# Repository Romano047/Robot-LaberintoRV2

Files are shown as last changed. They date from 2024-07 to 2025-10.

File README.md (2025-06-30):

# Robot-LaberintoRV2
Robot Laberinto R 2024-2025

Proyecto realizado en la Escuela de Educación Secundaria Técnica N°5 "2 de Abril" Temperley, Buenos Aires, Argentina. Desarrollado por Iván Romano, estudiante de Electrónica de la institución a cargo del profesor Ing. Martín Leguizamón.

El objetivo de este reoositrio es el de desarrollar un robot autónomo de competición dentro de la categoría de "Robot Laberinto". 

Se tomarán como referencia en su elaboración las reglas actualmente vigentes (2024) dentro de la Liga Nacional de Robótica (LNR) en la categoría de "Laberinto". 

# Guía de Repositorio

- Hardware
  - KiCad: En ella se encuentran todos los archivos correspondientes al desarrollo del PCB.

- 3D
  - AutoCad: En esta carpeta se encuentran los archivos correspondientes al diseño 3D en conjunto a sus trazados a formato .stl para facilitar su posterior impresión. 

- Software
  - Ensayos: Ensayos básicos de cada funcionalidad o punto de interés de forma aislada que conforman el robot. (A su vez se encontrarán en el archivos correspondientes al robort de competición provincial "Alita").
  - LaberintoR2_v2: Versión del Software ejecutada actualmente en el robot. 

# Especificaciones

- Software: Desarrollado en C Orientado a Objetos, por medio del uso de VsCode en conjunto a su extensión PlatformIO.
- Desarrollo de PCBs: KiCad 7
- Placa de Desarrollo: Espressif ESP-32 WROOM DEV KIT
- Sensores de proximidad: HC-SR04
- Drivers de Motores: TB6612fng

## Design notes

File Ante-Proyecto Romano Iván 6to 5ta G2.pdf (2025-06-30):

ESCUELA DE EDUCACION SECUNDARIA TECNICA N° 5

“2 DE ABRIL” – TEMPERLEY – BUENOS AIRES

### ROBOT LABERINTO 2.0

MATERIA : | MONTAJES DE PROYECTOS ELECTRÓNICOS
GRUPO : | SPACE ANGELS

AUTORES:

Alumnos: Nombre y mail:
Iván Romano - romanoivan@industrialdetemperley.edu.ar

NOTAS:

PROFESOR: ING. MARTIN LEGUIZAMON

# Robot Laberinto

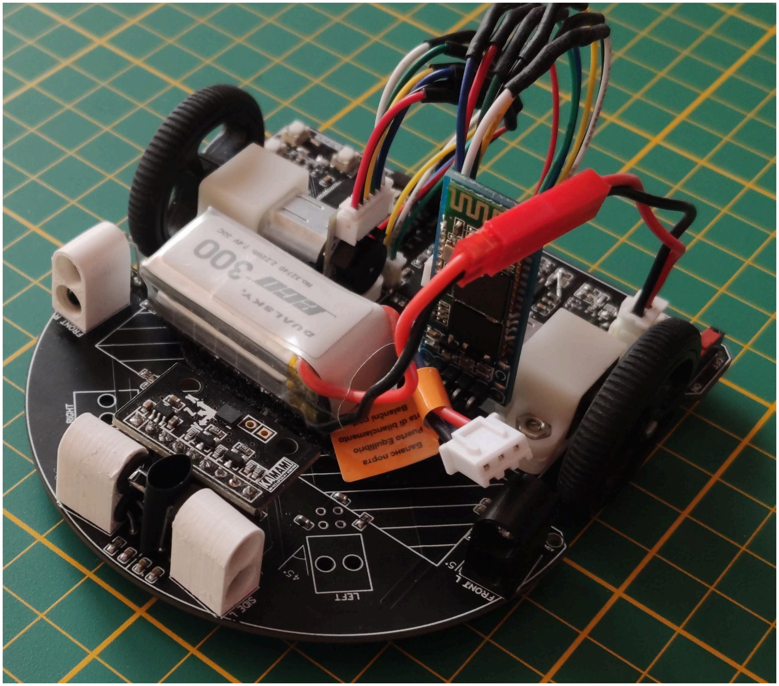
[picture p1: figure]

Robot laberinto capaz de evadir obstáculos y resolver caminos adversos de forma autónoma, con o sin asistencia parcial del usuario.

Este robot será sometido a situaciones en las que deberá decidir qué camino tomar, con tal de llegar a su objetivo nal en el menor tiempo posible y de la forma más eciente. Este decidirá según lo captado por los sensores. Contará con tres en total, uno al frente y dos a los laterales. Funcionan como una suerte de “ojos” con los que el robot reconocerá las paredes y los caminos libres para probar nuevas alternativas de resoluciones posibles.

Será programado por medio de Arduino, una IDE de código abierto, esto signica que es gratuito y accesible para todo el mundo. La placa de desarrollo empleada será el módulo ESP-32, el cual cuenta con Bluetooth y conexión wi, un controlador el cual cumplirá la función de ser el cerebro del proyecto. Este será quien controle y monitoree la información obtenida por los sensores, actuando en consecuencia, enviando órdenes a los motores, los cuales moverán al robot según lo observado.

Los motores serán los encargados de mover el robot según las órdenes enviadas por el módulo. El sentido de rotación será asignado por el “Puente H”, con el cual se regulará el sentido y la aceleración ordenada por medio de programación.

Este artefacto será alimentado por una batería LiPo de 7.4v apropiada para este tipo de elementos.

# ESQUEMA EN BLOQUES

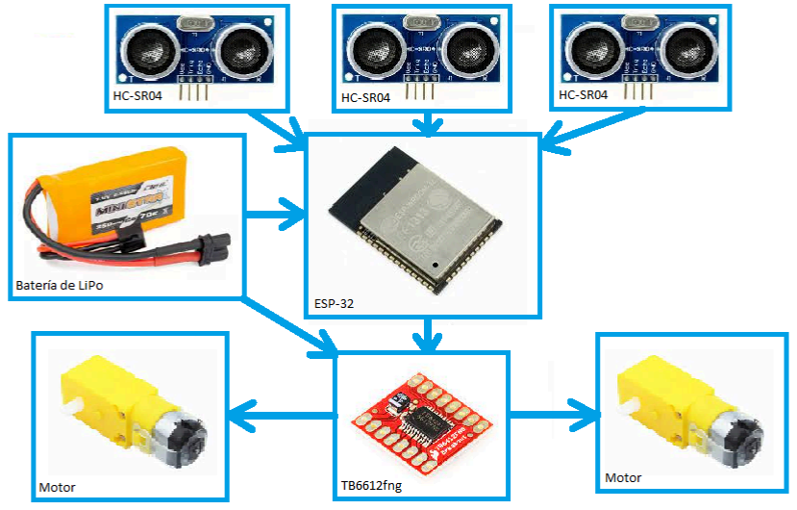
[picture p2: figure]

Materiales a emplear y precios

MATERIALES

Material | Cantidad | Elace | Precio | Final | U$D
ESP-32 Wroom | 1 | Starware (https://tienda.starware.com.ar/producto/placa-desarrollo-espressif-esp32-ch9102x-dual-core-wifi-bluetooth/) | $8,139 | $8,139 | $7,97
TB6612fng | 1 | Candy-Ho (https://candy-ho.com/producto/tb6612fng-driver-cnc-motor-paso-a-paso-router-arduino/) | $12,120 | $12,120 | $11,88
Motor Arduino | 2 | MercadoLibre (https://articulo.mercadolibre.com.ar/MLA-615832019-robotica-motor-dc-3v-6v-reductora-doble-eje-arduino-ptec-_JM) | $2,314 | $4,612 | $4,52
HC-SRO4 | 3 | MercadoLibre (https://articulo.mercadolibre.com.ar/MLA-1117802721-modulo-sensor-ultrasonido-hc-sr04-compatible-arduino-emakers-_JM) | $1,590 | $4,770 | $4,67
CNHL MiniStar 2S 350mA 7,4v | 1 | HobbyMotors (https://www.hobbymotors.com.ar/store/index.php?product_id=1314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) | $7,560 | $7,560 | $7,41
TOTAL | | | | $37,201 | $36,45

PCB Y ACCESORIOS

Material | Cantidad | Enlace | Precio | Final | U$D
Resistor SMD 0805 | 6 | MercadoLibre (https://articulo.mercadolibre.com.ar/MLA-813976300-resistencia-smd-0805-18w-5-10k-pack-x100-_JM) | $87 | $522 | $0.51
Capacitor Electrolítico 100uF 25v | 2 | MercadoLibre (https://articulo.mercadolibre.com.ar/MLA-727890697-capacitor-electrolitico-100uf-x-50v-105-8x14mm-pack-x10-_JM) | $570 | $1,140 | $1,11
Capacitor Multicapa 1uF | 2 | MercadoLibre (https://articulo.mercadolibre.com.ar/MLA-727757904-capacitor-multicapa-100nf-100000pf-1uf-x50v-pack-x10-_JM) | $355 | $710 | $0.69
Regulador 7805 | 1 | MercadoLibre (https://articulo.mercadolibre.com.ar/MLA-1400670817-regulador-7805cv-l7805cv-5v-15a-x-1-u-_JM) | $1,700 | $1,700 | $1,66
Plancha de cobre doble fas | 1 | — | — | — | —
Cloruro Férrico DELTA | 1 | MercadoLibre (https://articulo.mercadolibre.com.ar/MLA-750018369-cloruro-ferrico-concentrado-delta-fabricacion-circuitos-cl1-_JM) | $2,730 | $2,730 | $2,67
Conector Molex Hembra | 3 | MercadoLibre (https://articulo.mercadolibre.com.ar/MLA-1544835568-kit-x-30u-4-pin-terminal-molex-hembra-macho-y-pines-htec-_JM) | $260 | $780 | $0,76
Conector Molex Macho | 3 | MercadoLibre (https://articulo.mercadolibre.com.ar/MLA-1544835568-kit-x-30u-4-pin-terminal-molex-hembra-macho-y-pines-htec-_JM) | $260 | $780 | $0,76
TOTAL | | | | $8,362 | $8,19

Precios Totales

Categorías | Precio | U$D ($1020 pesos Arg)
MATERIALES | $37,201 | $36,45
PCB Y ACCESORIOS | $8,362 | $8,19
TOTAL | $45,563 | $44,64

Referencias de precios y respectiva equivalencia en dólares tomados en la 2da quincena de Marzo de 2024

# Tareas a realizar y Tiempos Estimados

1- Conseguir materiales a emplear para el desarrollo del proyecto (Una a dos semanas)

2- Realizar el diseño de esquemático y PCB mediante KiCad (Una semana)

3- Planchar, perforar, soldar PCB (Una semana)

4- Ensayos de Software preliminares (Una semana)

5- Realización y correcta ejecución del programa desarrollado (Dos a tres semanas)

6- Ajustes de programa (Una semana)

7- Implementación de mapeado observable por WiFi (Indenido)

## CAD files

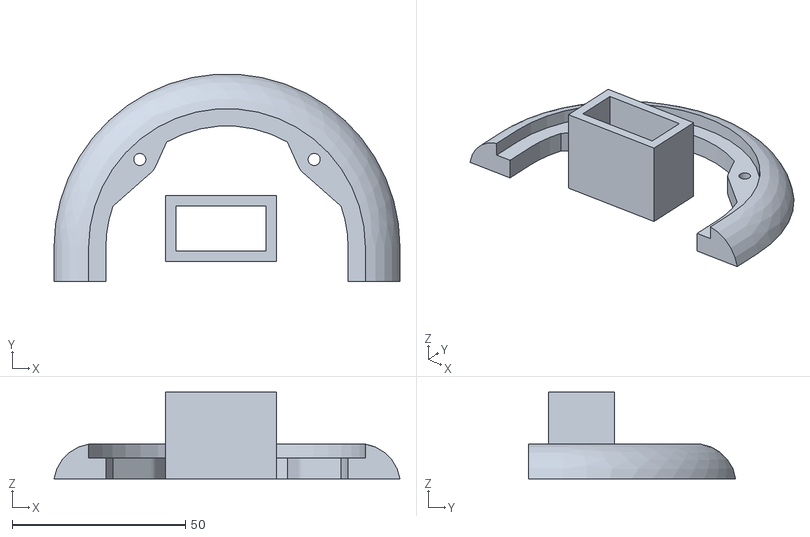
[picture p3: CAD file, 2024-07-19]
3D_Designs/AutoCad/LaverintoV2.stl/Paragolpes_LaberintoV2.stl
100.0 x 59.9 x 25.0

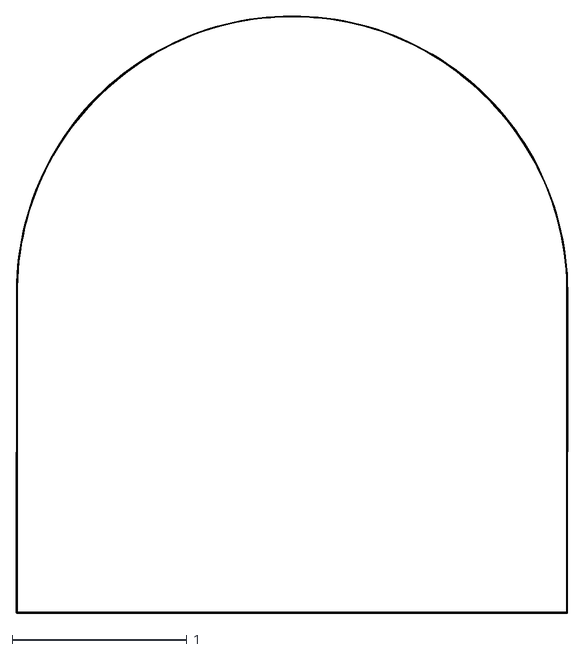
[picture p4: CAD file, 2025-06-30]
Hardware/KiCad/Trazado/DXF/Robot Laberinto 2.0-Edge_Cuts.dxf
3.16 x 3.42

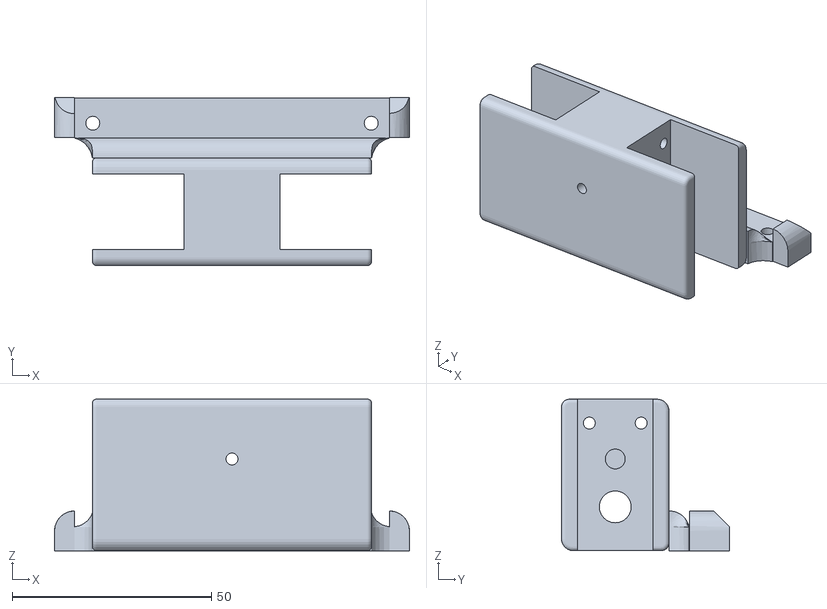
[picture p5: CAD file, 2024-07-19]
3D_Designs/AutoCad/LaverintoV2.stl/SoporteMA_LaberintoV2.stl
89.0 x 42.2 x 38.0

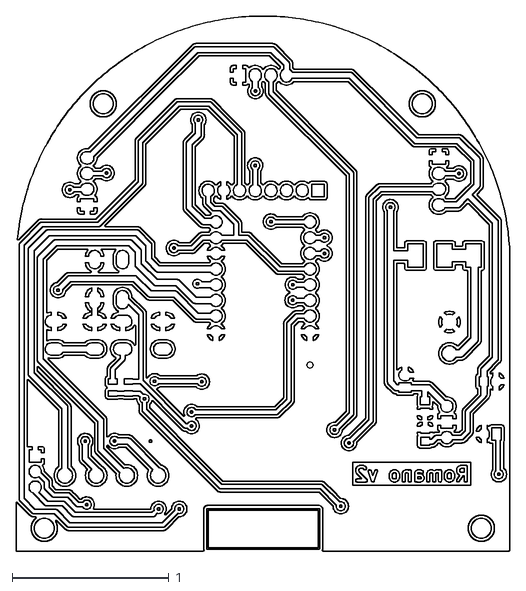
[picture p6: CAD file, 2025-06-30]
Hardware/KiCad/Trazado/DXF/Robot Laberinto 2.0-B_Cu.dxf
3.15 x 3.41

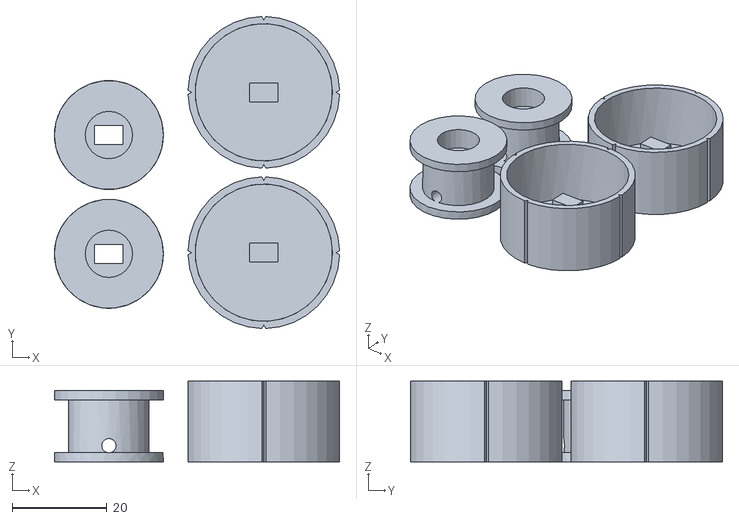
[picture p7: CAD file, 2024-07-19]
3D_Designs/AutoCad/LaverintoV2.stl/Ruedas_LaberintoV2_MA.stl
60.2 x 65.8 x 17.0

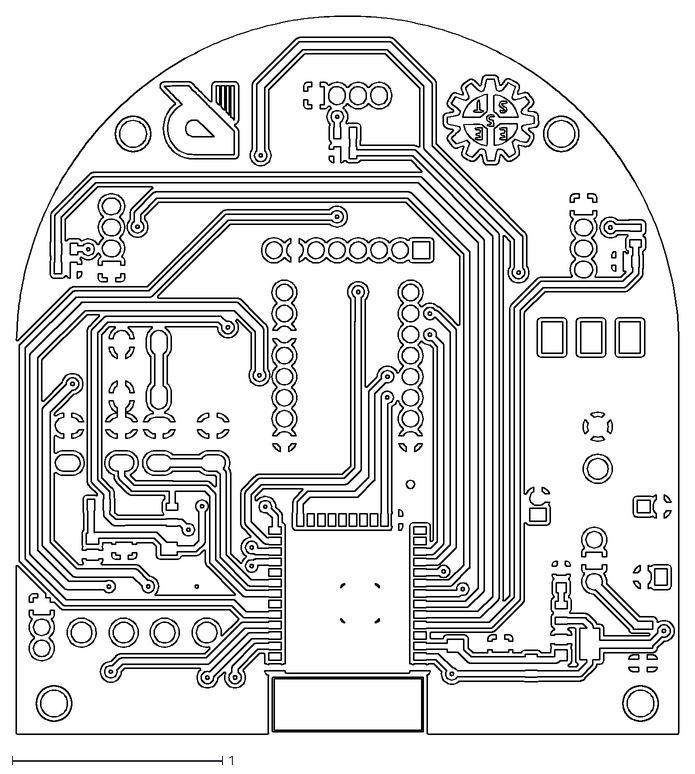
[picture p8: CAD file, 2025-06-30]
Hardware/KiCad/Trazado/DXF/Robot Laberinto 2.0-F_Cu.dxf
3.15 x 3.41

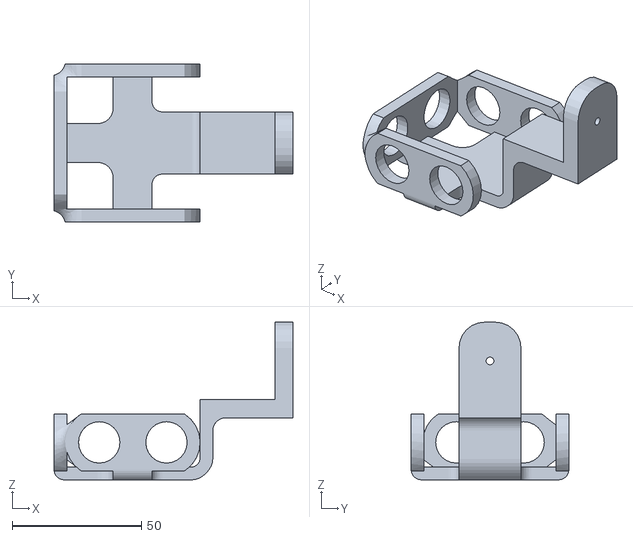
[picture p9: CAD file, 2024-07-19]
3D_Designs/AutoCad/LaverintoV2.stl/Ultrasonidos_LaberintoV2.stl
92.4 x 61.0 x 61.0

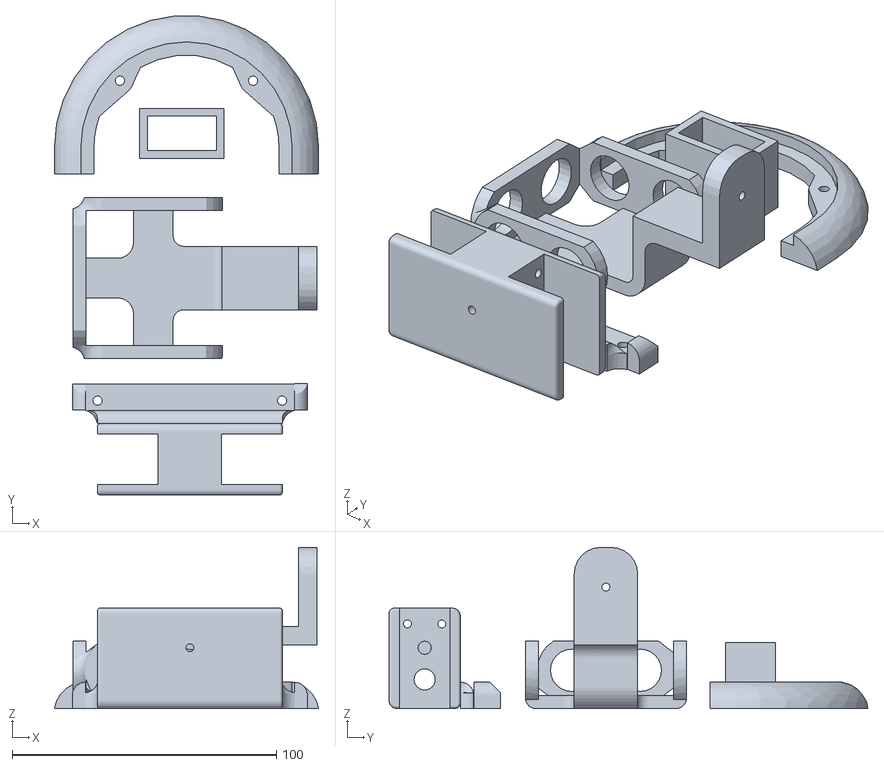
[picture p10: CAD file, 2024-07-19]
3D_Designs/AutoCad/LaverintoV2.stl/LaberintoV2_Completo.stl
100.0 x 181.2 x 61.0

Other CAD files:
3D_Designs/AutoCad/Ruedas_LaberintoV2_MA.dwg
3D_Designs/AutoCad/LaverintoV2_Completo.dwg
3D_Designs/AutoCad/LaberintoV2_1.dwg
Hardware/KiCad/Trazado/DXF/Bottom.dwg
Hardware/KiCad/Trazado/DXF/Robot Laberinto 2.0-B_Mask.dxf
Hardware/KiCad/Trazado/DXF/Robot Laberinto 2.0-B_Paste.dxf
Hardware/KiCad/Trazado/DXF/Robot Laberinto 2.0-B_Silkscreen.dxf
Hardware/KiCad/Trazado/DXF/Robot Laberinto 2.0-F_Mask.dxf
Hardware/KiCad/Trazado/DXF/Robot Laberinto 2.0-F_Paste.dxf
Hardware/KiCad/Trazado/DXF/Robot Laberinto 2.0-F_Silkscreen.dxf

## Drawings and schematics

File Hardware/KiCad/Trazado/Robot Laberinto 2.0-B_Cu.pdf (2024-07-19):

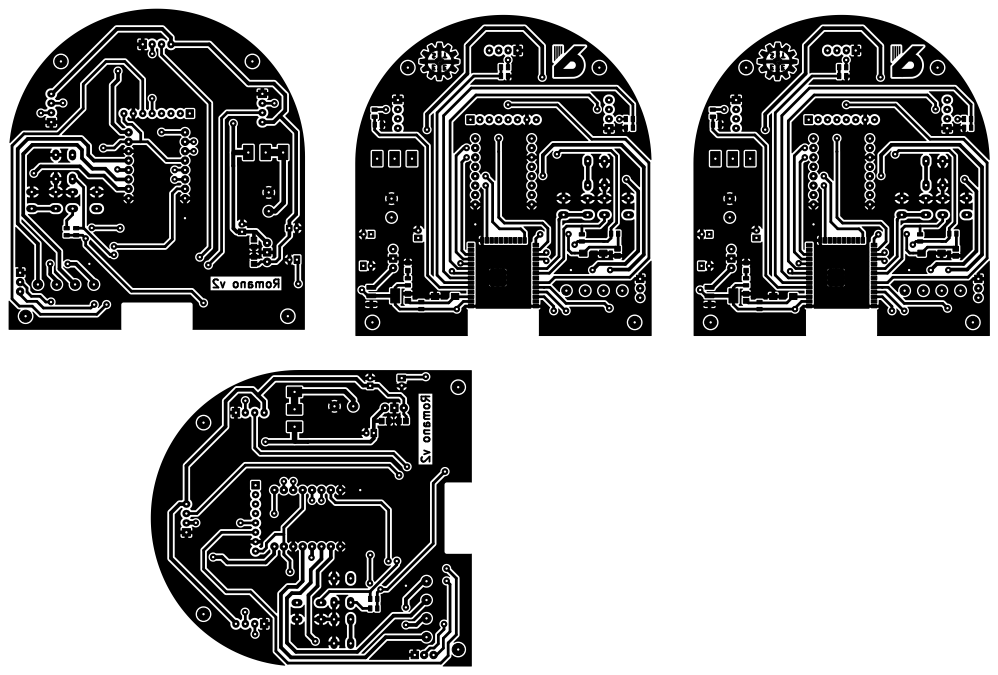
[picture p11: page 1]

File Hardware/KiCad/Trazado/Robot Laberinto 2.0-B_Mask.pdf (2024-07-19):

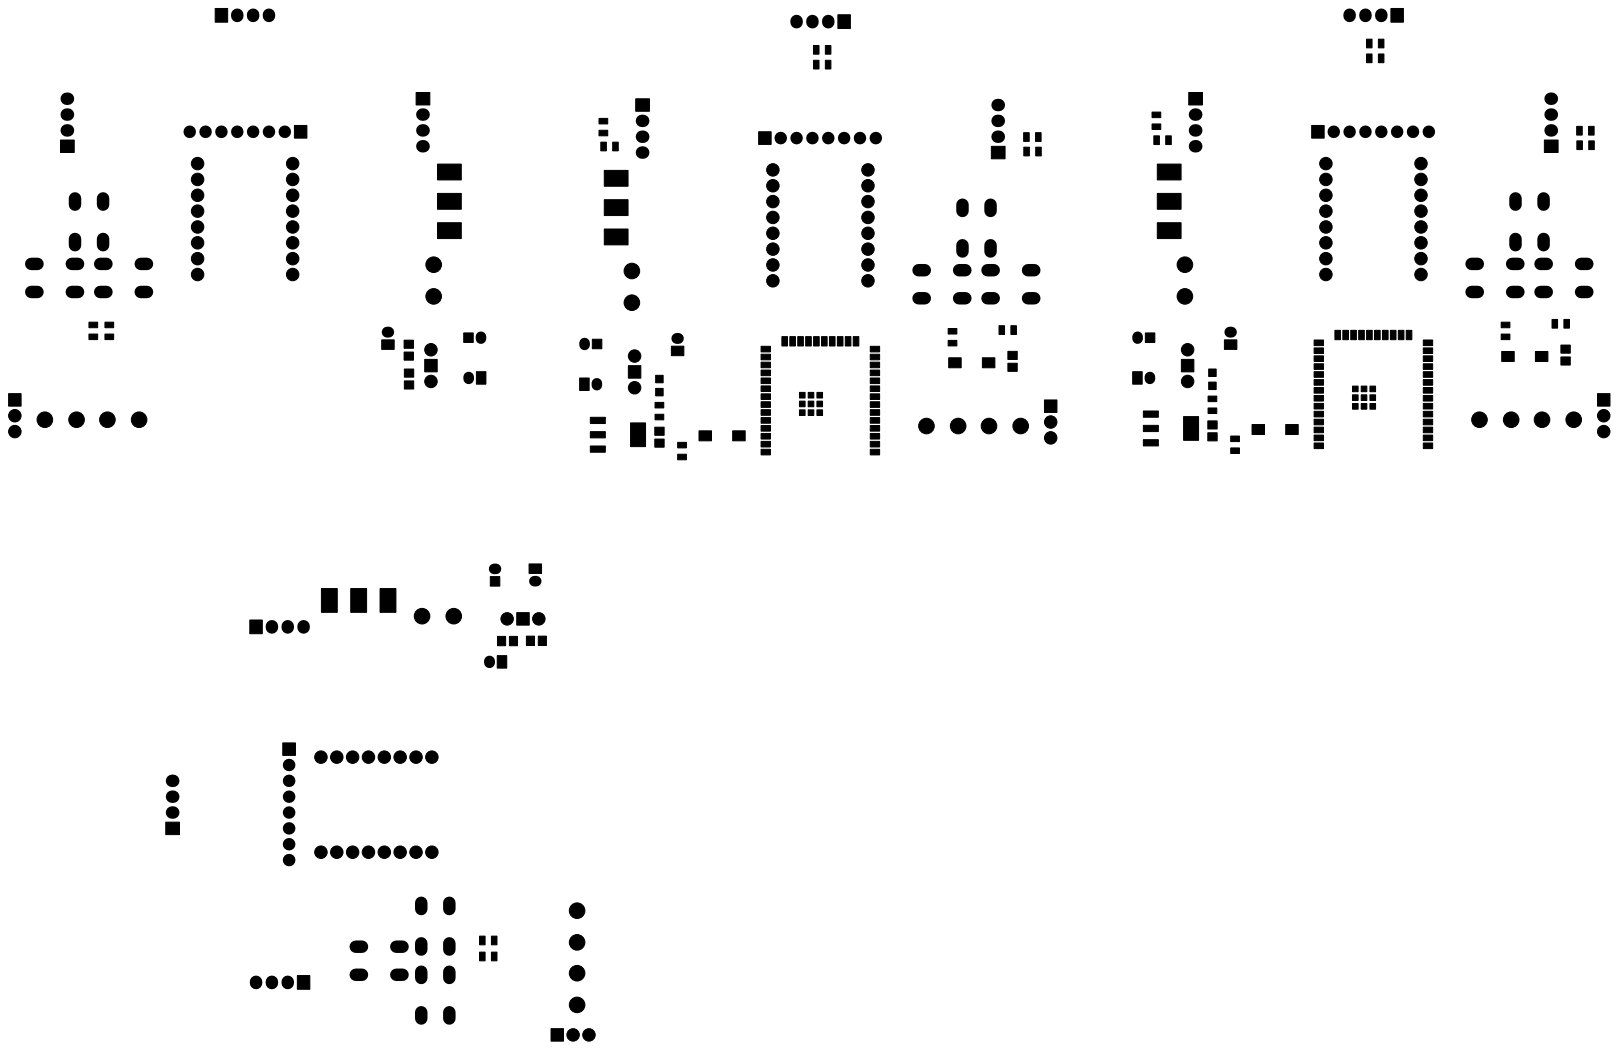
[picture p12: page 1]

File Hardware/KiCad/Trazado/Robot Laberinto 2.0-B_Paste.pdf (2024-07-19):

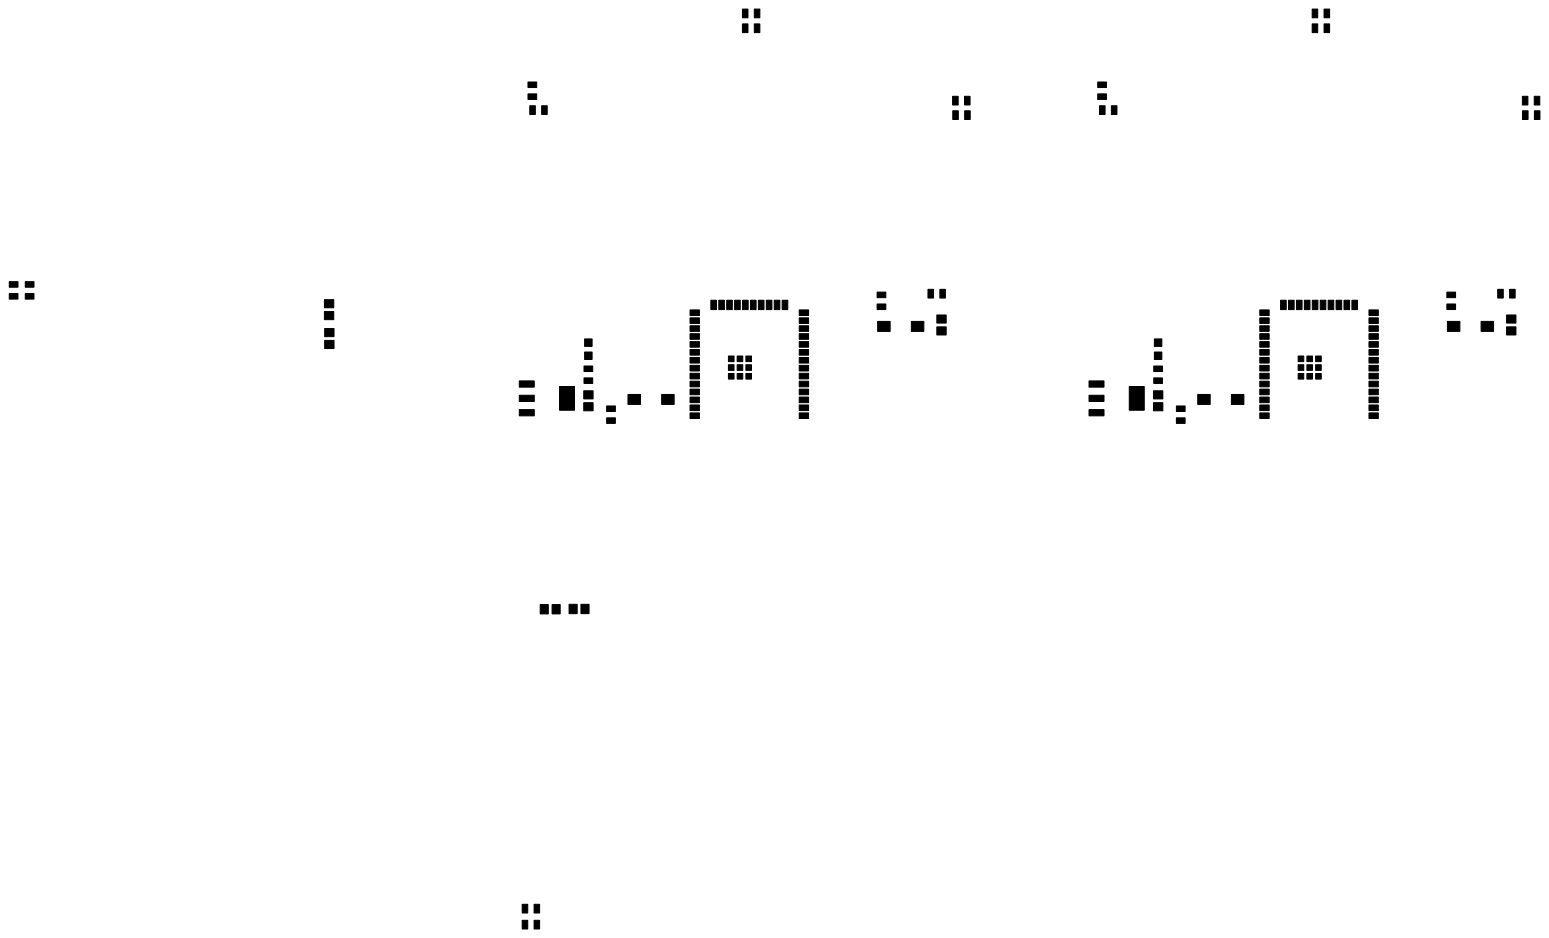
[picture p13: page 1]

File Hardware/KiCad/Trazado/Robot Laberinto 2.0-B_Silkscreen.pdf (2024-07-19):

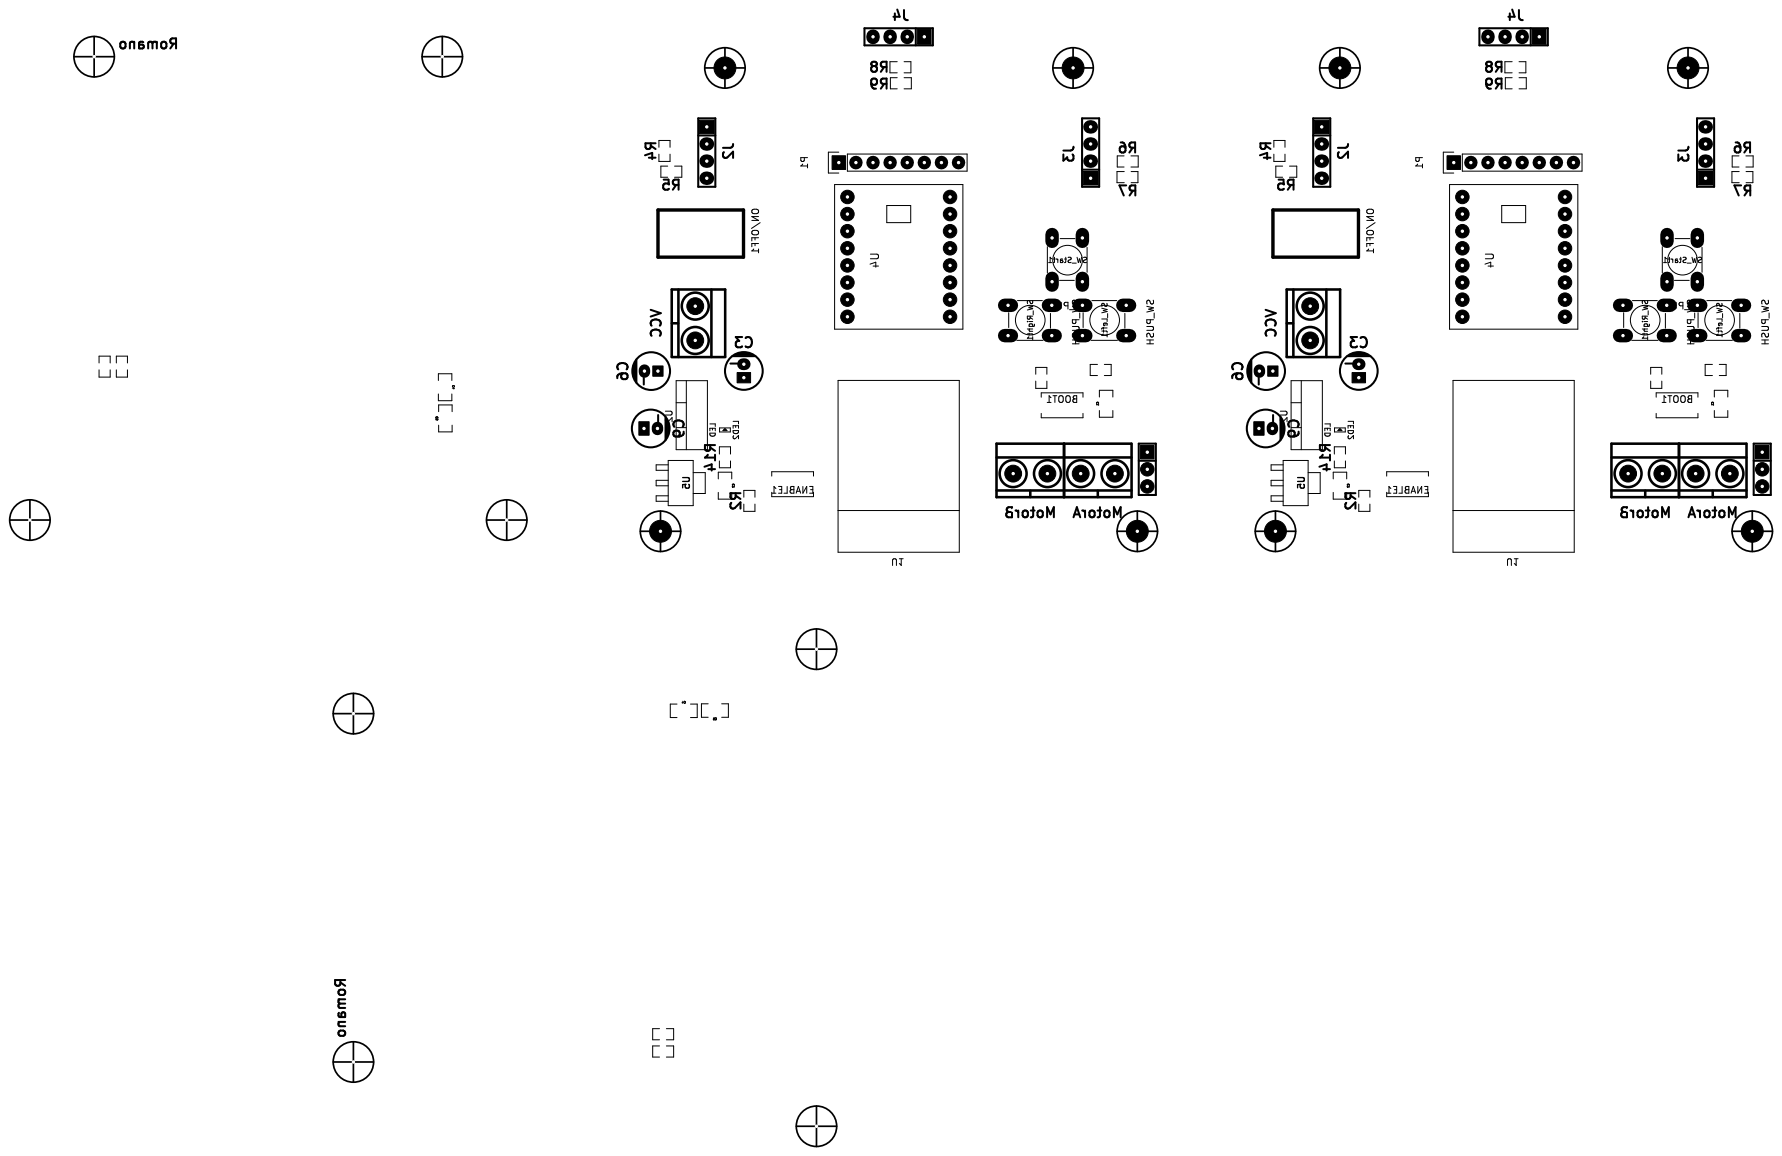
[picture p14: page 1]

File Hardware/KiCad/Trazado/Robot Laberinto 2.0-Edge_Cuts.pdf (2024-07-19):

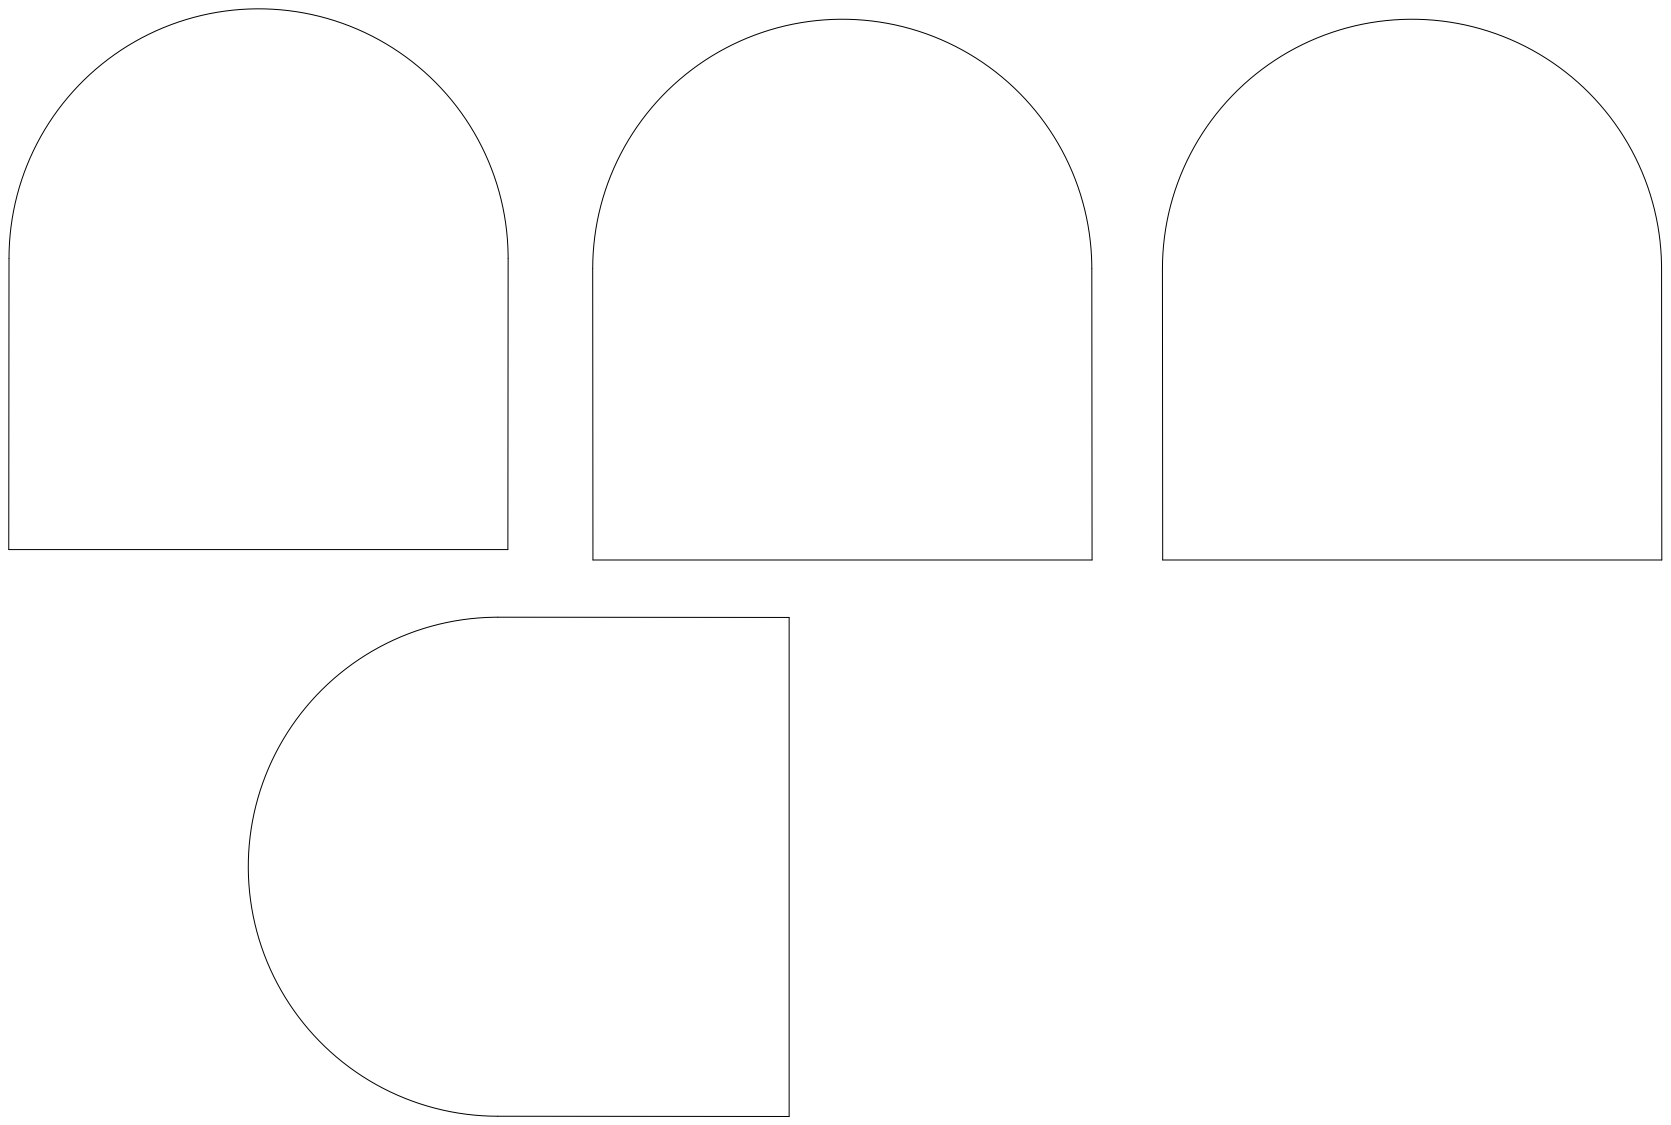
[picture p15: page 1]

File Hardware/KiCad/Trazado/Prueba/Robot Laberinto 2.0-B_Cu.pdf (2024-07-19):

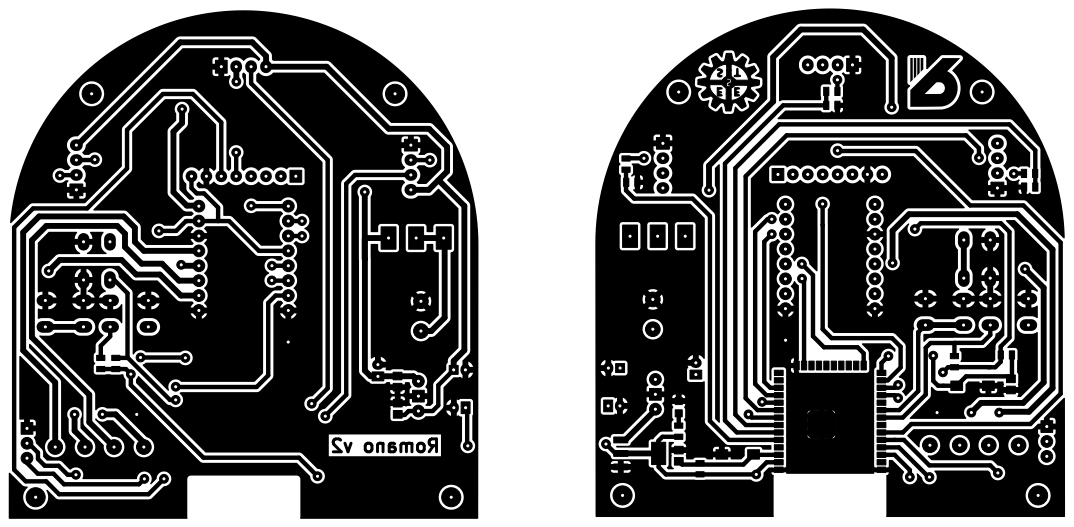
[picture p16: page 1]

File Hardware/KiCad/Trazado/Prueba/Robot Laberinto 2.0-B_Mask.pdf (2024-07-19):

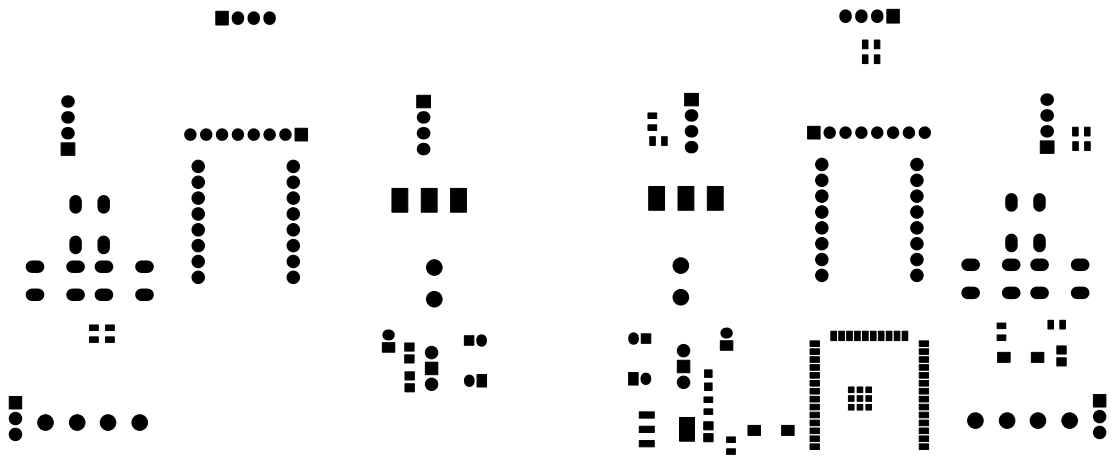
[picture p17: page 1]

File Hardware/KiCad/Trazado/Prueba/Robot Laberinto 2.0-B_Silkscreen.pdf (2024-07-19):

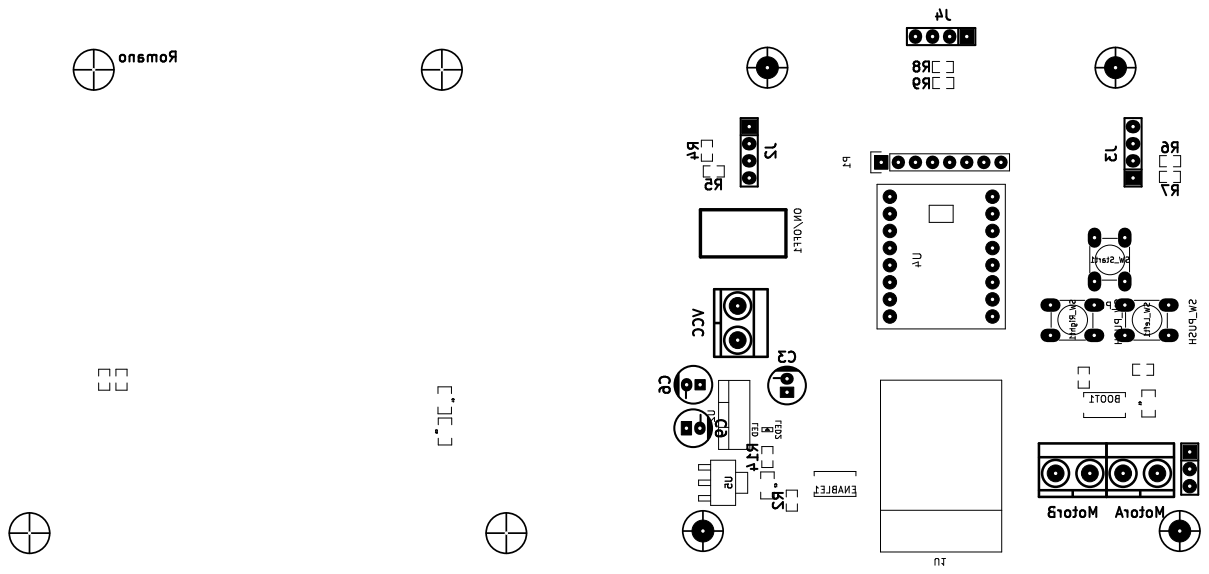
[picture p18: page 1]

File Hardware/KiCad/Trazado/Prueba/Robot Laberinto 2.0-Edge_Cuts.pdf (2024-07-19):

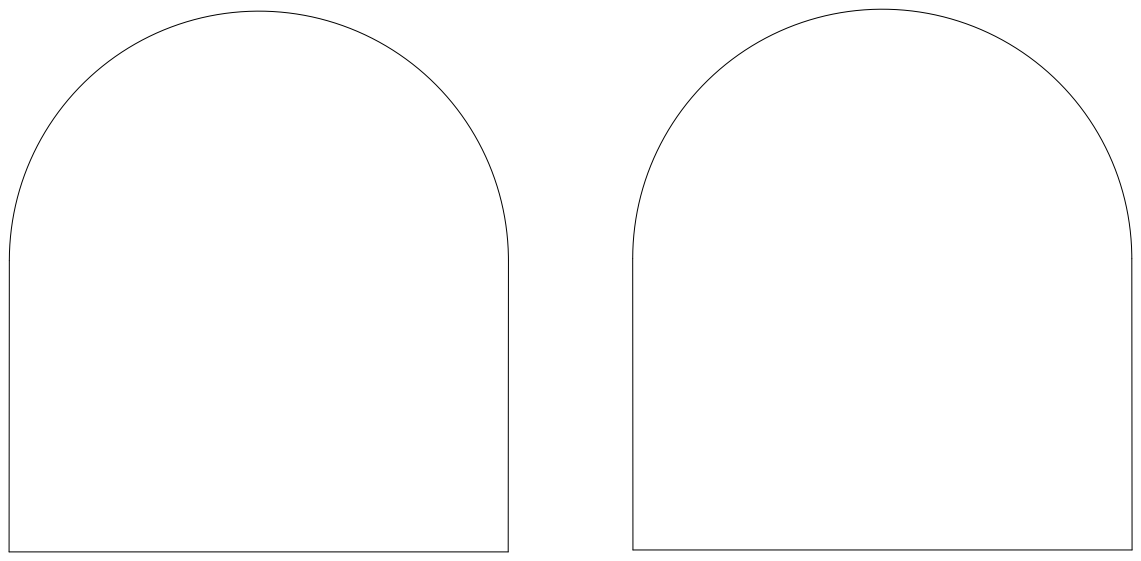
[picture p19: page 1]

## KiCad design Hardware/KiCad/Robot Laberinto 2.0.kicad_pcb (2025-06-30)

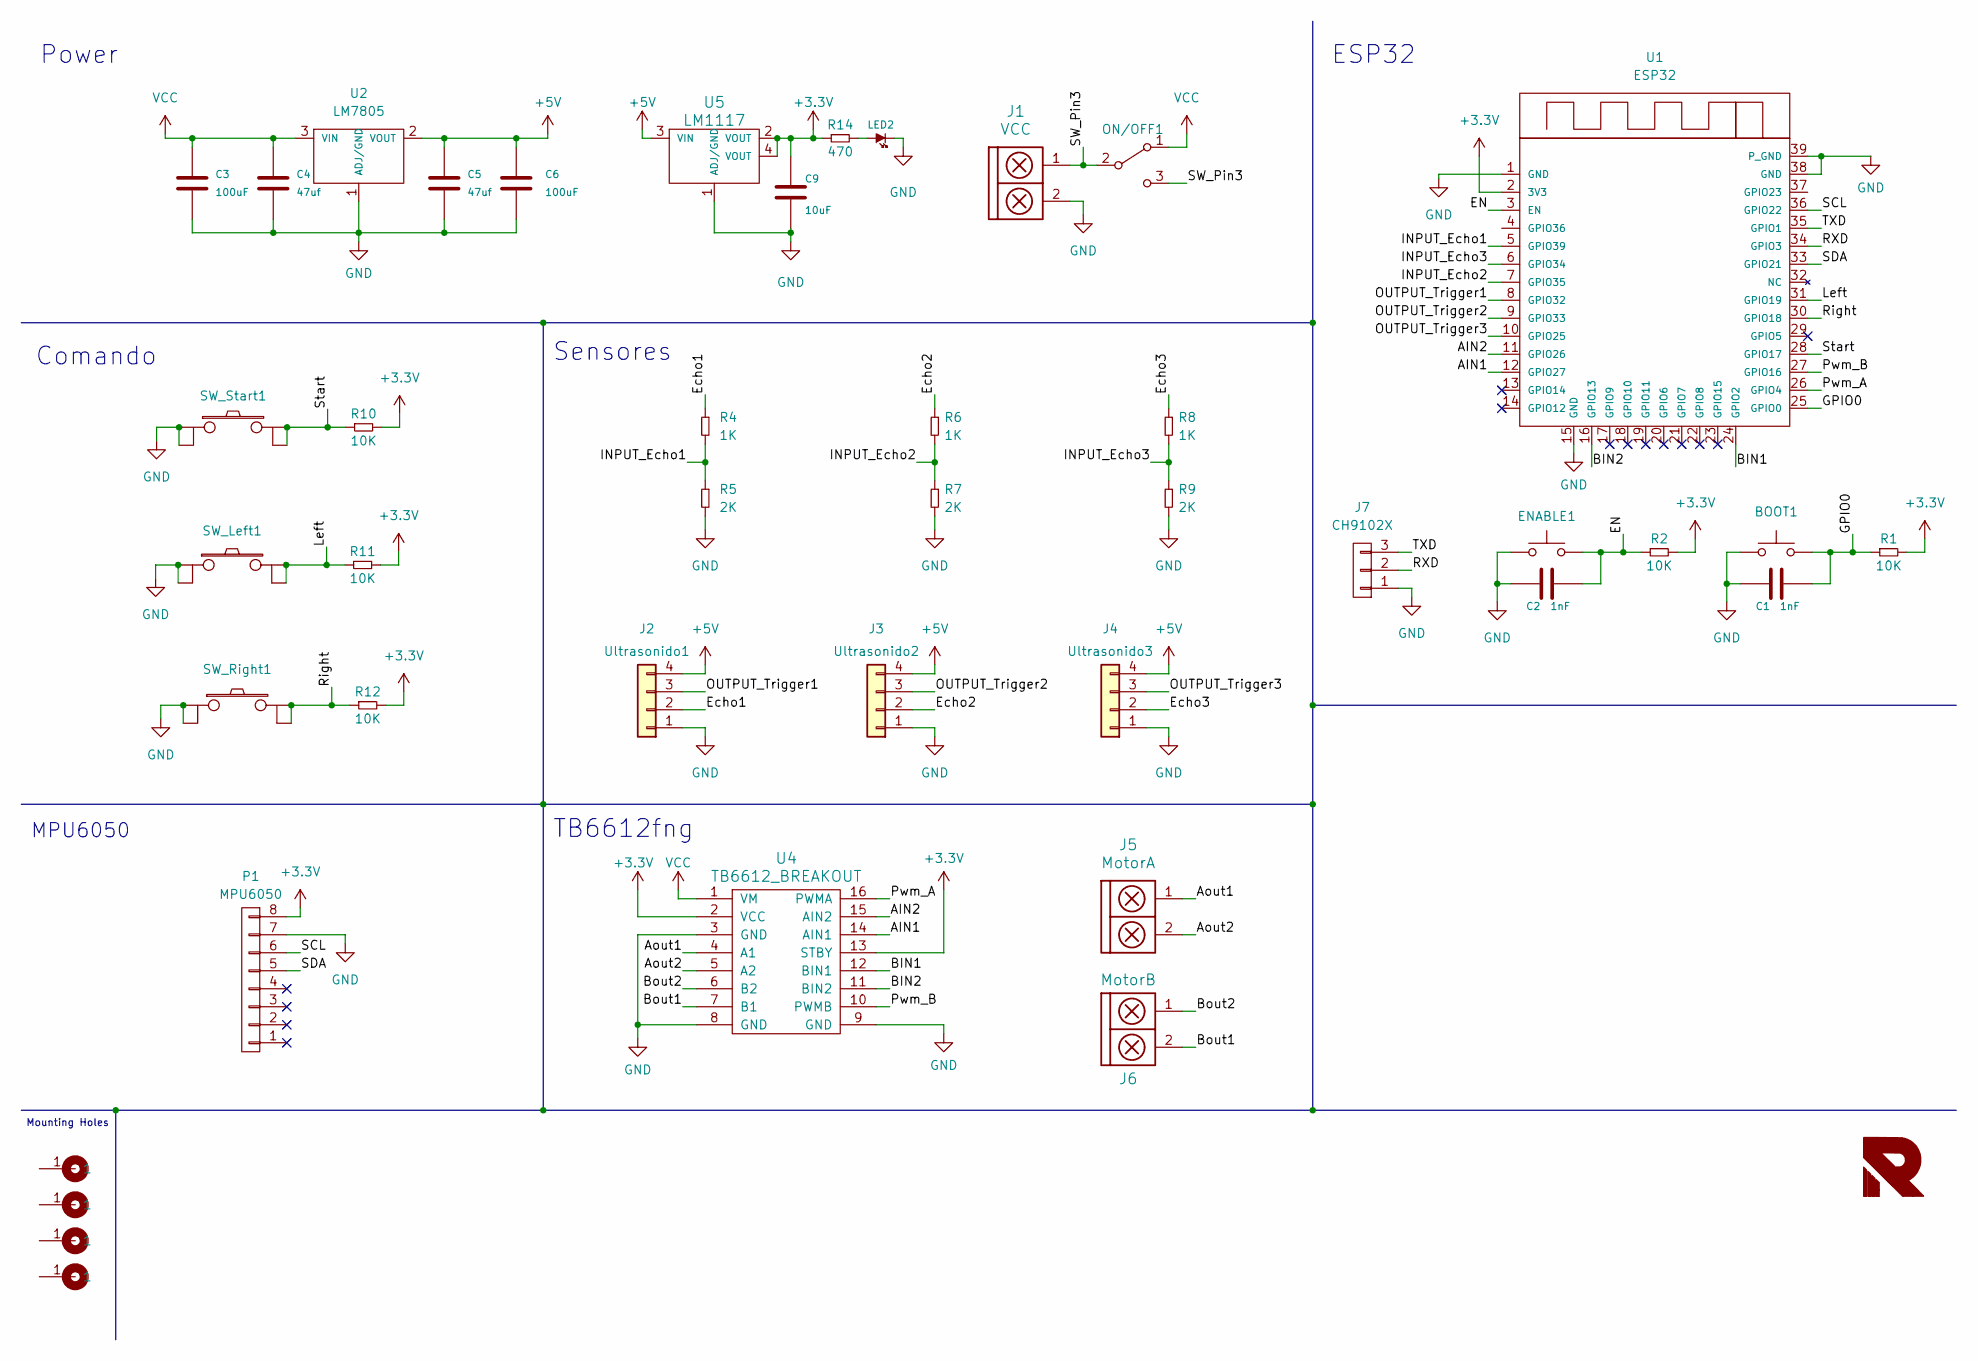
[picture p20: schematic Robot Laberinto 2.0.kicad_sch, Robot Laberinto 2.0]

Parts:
BOOT1: SW_Push; SW_SPST_EVQPE1
C1, C2: 1nF; C_0805
C3, C6: 100uF; CAP_ELEC_5x11mm
C4, C5: 47uf; C_0805
C9: 10uF; CAP_ELEC_5x11mm
ENABLE1: SW_Push; SW_SPST_EVQPE1
J1: VCC; BORNERA2_AZUL
J2: Ultrasonido1; pin_strip_4
J3: Ultrasonido2; pin_strip_4
J4: Ultrasonido3; pin_strip_4
J5: MotorA; BORNERA2_AZUL
J6: MotorB; BORNERA2_AZUL
J7: CH9102X; Pin_Strip_3
J8, J9, J10, J11: Cable_PAD; Separador_M3_5mm
LED2: LED; Led_0805
ON/OFF1: SW_SPDT; SW_SPDT_TH_Vertical
P1: MPU6050; Pin_Header_Straight_1x08
R1, R2, R10, R11, R12: 10K; R_0805
R4, R6, R8: 1K; R_0805
R5, R7, R9: 2K; R_0805
R14: 470; R_0805
SW_Left1: SW_PUSH; PUSH_SWITCH_THT
SW_Right1: SW_PUSH; PUSH_SWITCH_THT
SW_Start1: SW_PUSH; PUSH_SWITCH_THT
U1: ESP32; ESP32-WROOM-32_MacroLib
U2: LM7805; TO-220
U4: TB6612_BREAKOUT; TB6612_Breakout
U5: LM1117; SOT223

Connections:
+3.3V: C9.1, P1.8, R1.2, R2.2, R10.2, R11.2, R12.2, R14.1, U1.2 (3V3), U4.2 (VCC), U4.13 (STBY), U5.2 (VOUT), U5.4 (VOUT)
+5V: C5.1, C6.1, J2.4, J3.4, J4.4, U2.2 (VOUT), U5.3 (VIN)
/AIN1: U1.12 (GPIO27), U4.14 (AIN1)
/AIN2: U1.11 (GPIO26), U4.15 (AIN2)
/Aout1: J5.1, U4.4 (A1)
/Aout2: J5.2, U4.5 (A2)
/BIN1: U1.24 (GPIO2), U4.12 (BIN1)
/BIN2: U1.16 (GPIO13), U4.11 (BIN2)
/Bout1: J6.2, U4.7 (B1)
/Bout2: J6.1, U4.6 (B2)
/EN: C2.2, ENABLE1.2, R2.1, U1.3 (EN)
/Echo1: J2.2, R4.1
/Echo2: J3.2, R6.1
/Echo3: J4.2, R8.1
/GPIO0: BOOT1.2, C1.2, R1.1, U1.25 (GPIO0)
/INPUT_Echo1: R4.2, R5.1, U1.5 (GPIO39)
/INPUT_Echo2: R6.2, R7.1, U1.7 (GPIO35)
/INPUT_Echo3: R8.2, R9.1, U1.6 (GPIO34)
/Left: R11.1, SW_Left1.3, SW_Left1.4, U1.31 (GPIO19)
/OUTPUT_Trigger1: J2.3, U1.8 (GPIO32)
/OUTPUT_Trigger2: J3.3, U1.9 (GPIO33)
/OUTPUT_Trigger3: J4.3, U1.10 (GPIO25)
/Pwm_A: U1.26 (GPIO4), U4.16 (PWMA)
/Pwm_B: U1.27 (GPIO16), U4.10 (PWMB)
/RXD: J7.2, U1.34 (GPIO3)
/Right: R12.1, SW_Right1.3, SW_Right1.4, U1.30 (GPIO18)
/SCL: P1.6, U1.36 (GPIO22)
/SDA: P1.5, U1.33 (GPIO21)
/SW_Pin3: J1.1, ON/OFF1.2 (B), ON/OFF1.3 (C)
/Start: R10.1, SW_Start1.3, SW_Start1.4, U1.28 (GPIO17)
/TXD: J7.3, U1.35 (GPIO1)
GND: BOOT1.1, C1.1, C2.1, C3.2, C4.2, C5.2, C6.2, C9.2, ENABLE1.1, J1.2, J2.1, J3.1, J4.1, J7.1, LED2.2 (K), P1.7, R5.2, R7.2, R9.2, SW_Left1.1, SW_Left1.2, SW_Right1.1, SW_Right1.2, SW_Start1.1, SW_Start1.2, U1.1 (GND), U1.15 (GND), U1.38 (GND), U1.39 (P_GND), U2.1 (ADJ/GND), U4.3 (GND), U4.8 (GND), U4.9 (GND), U5.1 (ADJ/GND)
unnamed: LED2.1 (A), R14.2
VCC: C3.1, C4.1, ON/OFF1.1 (A), U2.3 (VIN), U4.1 (VM)

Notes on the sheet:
Sensores
Comando
Mounting Holes
MPU6050
TB6612fng
ESP32
Power

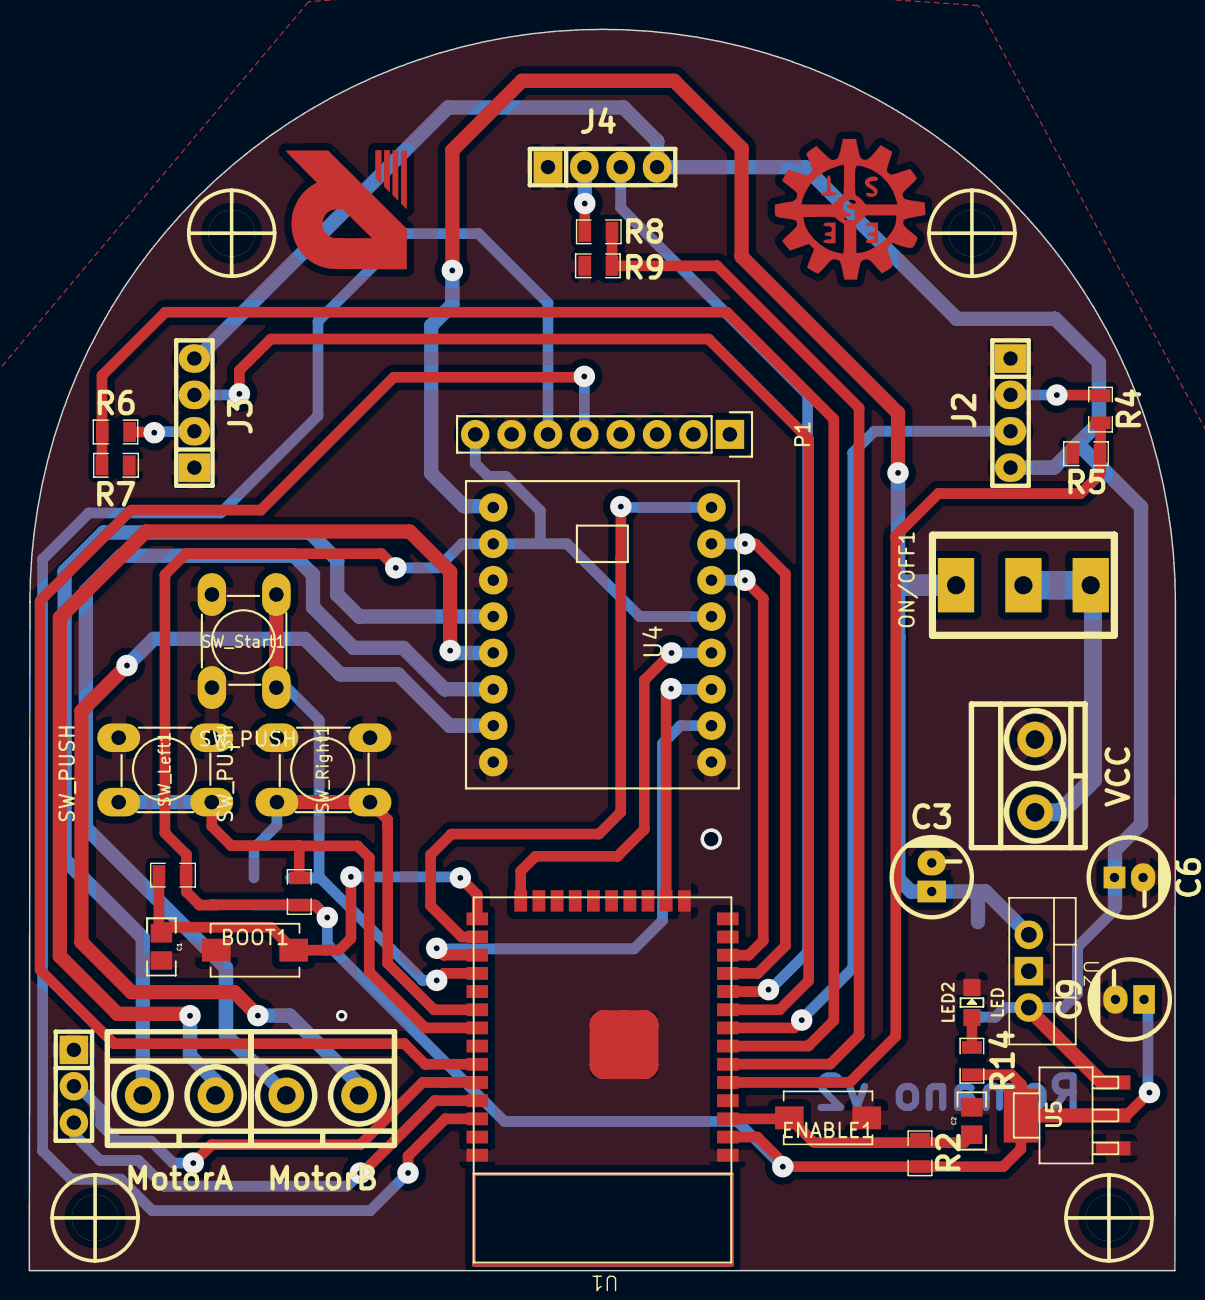
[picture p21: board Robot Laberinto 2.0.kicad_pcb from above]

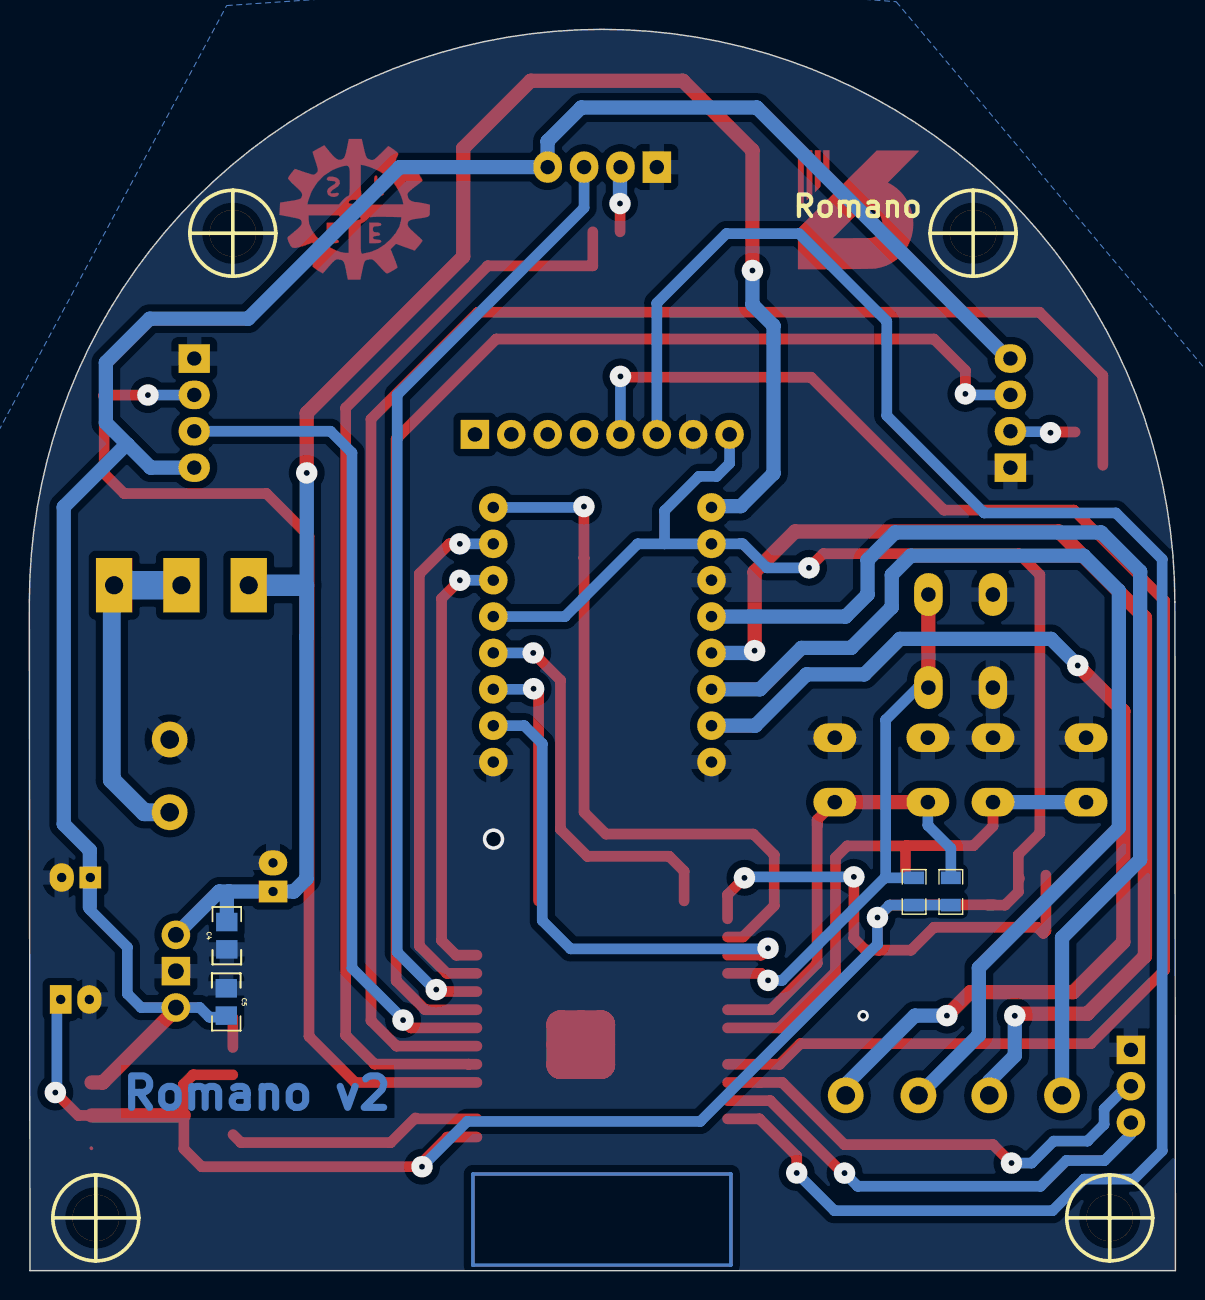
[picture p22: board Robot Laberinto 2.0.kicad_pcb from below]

Board: 2 copper layers, 80.0 x 86.7 mm, 43 parts (5 on the bottom side), 34 nets.

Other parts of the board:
Romano: LOGO; LOGO R INVERTIDO

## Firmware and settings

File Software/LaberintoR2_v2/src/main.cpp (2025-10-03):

#include <Arduino.h>
#include <Wire.h>
#include <math.h>
#include <BluetoothSerial.h>
#include <motors_TB6612fng.h>
#include "I2Cdev.h"
#include "MPU6050.h"

//Distance Sensors
#define PIN_ECHO_R        39 
#define PIN_ECHO_L        35 
#define PIN_ECHO_FRONT    34 
#define PIN_TRIGGER_R     32 
#define PIN_TRIGGER_L     33 
#define PIN_TRIGGER_FRONT 25 
//Switches
#define PIN_START 17
#define PIN_RIGHT 18
#define PIN_LEFT  19
//Motor Drivers
#define PIN_B1    27
#define PIN_B2    26
#define PIN_A1     2
#define PIN_A2    13
#define PIN_PWM_B  4
#define PIN_PWM_A 16

#define CHANNEL_MR 0
#define CHANNEL_ML 1 
#define PWM_FREQUENCY 1000 
#define PWM_RESOLUTION 8

MotorPair motor (PIN_A1 , PIN_A2 , PIN_PWM_A , CHANNEL_MR ,
                 PIN_B1 , PIN_B2 , PIN_PWM_B , CHANNEL_ML ,
                 PWM_FREQUENCY , PWM_RESOLUTION);


//Bluetooth
const char *pin = "1234";
String device_name = "Romano v2";
#if !defined(CONFIG_BT_ENABLED) || !defined(CONFIG_BLUEDROID_ENABLED)
#error Bluetooth is not enabled! Please run `make menuconfig` to and enable it
#endif
#if !defined(CONFIG_BT_SPP_ENABLED)
#error Serial Bluetooth not available or not enabled. It is only available for the ESP32 chip.
#endif
BluetoothSerial SerialBT;
int dato_BT;


// La dirección del MPU6050 puede ser 0x68 o 0x69, dependiendo 
// del estado de AD0. Si no se especifica, 0x68 estará implicito
MPU6050 sensor;

// Valores RAW (sin procesar) del acelerometro y giroscopio en los ejes x,y,z
int16_t gx, gy, gz;

long tiempo_prev, dt;
float girosc_ang_x, girosc_ang_y;
float girosc_ang_x_prev, girosc_ang_y_prev;



void setup() {
  Serial.begin (115200);

  //Switches
  pinMode (PIN_START , INPUT_PULLDOWN);
  pinMode (PIN_LEFT  , INPUT_PULLDOWN);
  pinMode (PIN_RIGHT , INPUT_PULLDOWN);

  //Distance Sensors
  pinMode (PIN_ECHO_R , INPUT);
  pinMode (PIN_ECHO_L , INPUT);
  pinMode (PIN_ECHO_FRONT , INPUT);
  pinMode (PIN_TRIGGER_R  , OUTPUT);
  pinMode (PIN_TRIGGER_L  , OUTPUT);
  pinMode (PIN_TRIGGER_FRONT , OUTPUT);

  digitalWrite (PIN_TRIGGER_R , LOW);
  digitalWrite (PIN_TRIGGER_L , LOW);
  digitalWrite (PIN_TRIGGER_FRONT , LOW);


  //Bluetooth
  SerialBT.begin(device_name);
  Serial.printf("The device with name \"%s\" is started.\nNow you can pair it with Bluetooth!\n", device_name.c_str());

  #ifdef USE_PIN
    SerialBT.setPin(pin);
    Serial.println("Using PIN");
  #endif

  //MPU6050
  Wire.begin();       
  sensor.initialize(); 
  if (sensor.testConnection()) Serial.println("Sensor iniciado correctamente");
  else Serial.println("Error al iniciar el sensor");
  tiempo_prev=millis();
}


void Bluetooth() {
  if (Serial.available()) {
    SerialBT.write(Serial.read());
  }
  if (SerialBT.available()) {
    Serial.write(SerialBT.read());
  }
  delay(20);

  dato_BT = SerialBT.read();
}



int Read_MPU6050() {
  // Leer las velocidades angulares 
  sensor.getRotation(&gx, &gy, &gz);
  
  //Calcular los angulos rotacion:
  
  dt = millis()-tiempo_prev;
  tiempo_prev=millis();
  
  girosc_ang_x = (gx/131)*dt/1000.0 + girosc_ang_x_prev;
  girosc_ang_y = (gy/131)*dt/1000.0 + girosc_ang_y_prev;

  girosc_ang_x_prev=girosc_ang_x;
  girosc_ang_y_prev=girosc_ang_y;

  //Mostrar los angulos separadas por un [tab]
  Serial.print("Rotacion en X:  ");
  Serial.print(girosc_ang_x); 
  Serial.print("tRotacion en Y: ");
  Serial.println(girosc_ang_y);
  delay(10);

  return girosc_ang_x;
}


#define MAX_LEFT       255
#define MAX_RIGHT      190
#define MID_SPEED      140
#define LOW_SPEED       70
#define BREAK            0
#define WALL_DETECTED_FRONT  500
#define WALL_DETECTED_SIDES 1000
#define SIDE_SETPOINT 500
#define SETPOINT 25

int Read_Front_Sensor () {
  digitalWrite (PIN_TRIGGER_FRONT , HIGH);
  delayMicroseconds (10);
  digitalWrite (PIN_TRIGGER_FRONT , LOW);
  int time = pulseIn (PIN_ECHO_FRONT , HIGH);
  
  return time;
}

int Read_Left_Sensor () {
  digitalWrite (PIN_TRIGGER_L , HIGH);
  delayMicroseconds (10);
  digitalWrite (PIN_TRIGGER_L , LOW);
  int time = pulseIn (PIN_ECHO_L , HIGH);

  return time;
}

int Read_Right_Sensor () {
  digitalWrite (PIN_TRIGGER_R , HIGH);
  delayMicroseconds (10);
  digitalWrite (PIN_TRIGGER_R , LOW);
  int time = pulseIn (PIN_ECHO_R , HIGH);

  return time;
}




bool front_wall_detected (int sensor) {
  if (sensor < WALL_DETECTED_FRONT) {
    return true;
  } else {
    return false;
  }
}

bool side_wall_detected (int sensor) {
  if (sensor < WALL_DETECTED_SIDES) {
    return true;
  } else {
    return false;
  }
}

bool side_setpoint_reached (int sensor) {
  if (sensor <= SIDE_SETPOINT) {
    return true;
  } else {
    return false;
  }
}


bool button_order (int button) {
  int button_read = digitalRead (button);

  if (button_read == LOW) {
    return true;
  } else {
    return false;
  }
}




int setPoint = SETPOINT;
int position;

int proportional;
int derivative;
int integral;
int lastError;

int maxSpeed = 255;
int minSpeed = 205;
int speed    = 235;

float kp = 0.70;
float ki =    0;
float kd = 0.18;
float pid;
float pidRight;
float pidLeft;
int crash = 0;

#define RIGHT_MOTOR_PWM_ERROR 65

void PID (int wall_sensor) {

  crash = 0;

  position = wall_sensor;

  proportional = position - setPoint;
  derivative = proportional - lastError;

  pid = (proportional * kp) + (derivative * kd);

  lastError = proportional;

  pidRight = speed + pid;
  pidLeft = speed - pid;

  if (pidRight > maxSpeed) {
    pidRight = maxSpeed;
  }
  if (pidLeft > maxSpeed) {
    pidLeft = maxSpeed;
  }

  if (pidRight <= minSpeed && pidLeft > minSpeed){
    motor.TurnRight(minSpeed + (minSpeed - pidRight), pidLeft);
  }
  else if (pidLeft <= minSpeed && pidRight > minSpeed) {
    motor.TurnLeft(pidRight, minSpeed + (minSpeed - pidLeft));
  }
  else {
    motor.MoveForwards(pidRight - RIGHT_MOTOR_PWM_ERROR , pidLeft);
  }
}

bool robot_is_turning = false;
bool turning_left  = false;
bool turning_right = false;

void TurnLeftPerLeft (int left_sensor) {
  motor.TurnLeft (LOW_SPEED , MAX_RIGHT);

  if (side_setpoint_reached (left_sensor)) {
    turning_left = false;
  }
}

void TurnRightPerLeft (int left_sensor) {
  motor.TurnRight (MAX_LEFT , BREAK);

  if (side_setpoint_reached (left_sensor)) {
    turning_right = false;
  }
}

void TurnRightPerRight (int right_sensor) {
  motor.TurnRight (MAX_LEFT , LOW_SPEED);

  if (side_setpoint_reached (right_sensor)) {
    turning_right = false;
  }
}

void TurnLeftPerRight (int right_sensor) {
  motor.TurnLeft (BREAK , MAX_RIGHT);

  if (side_setpoint_reached (right_sensor)) {
    turning_right = false;
  }
}


void FollowLeftWall () {
  int front = Read_Front_Sensor();
  int left  =  Read_Left_Sensor();

  if (!robot_is_turning) {
    if (side_wall_detected (left)) {
      if (front_wall_detected (front)) {
        robot_is_turning = true;
        turning_right = true;
      }
      else {
        PID (left);
      }
    }
    else {
      robot_is_turning = true;
      turning_left = true;
    }
  }

  else {

    if (turning_left) {
      TurnLeftPerLeft (left);
      if (!turning_left) {
        robot_is_turning = false;
      }
    }

    if (turning_right) {
      TurnRightPerLeft (left);
      if (!turning_right) {
        robot_is_turning = false;
      }
    }
  }


  if (front < 340) {
    motor.MoveBackwards (MAX_LEFT , MAX_RIGHT);
    delay (150);
    motor.TurnRight (MAX_LEFT , BREAK);
    delay (150);
    crash = crash + 1;
  }

  if (crash > 5) {
    motor.MoveBackwards (MAX_LEFT , MAX_RIGHT);
    delay (350);
    motor.TurnRight (MAX_LEFT , BREAK);
    delay (400);
    crash = 0;
  }
}


void FollowRightWall () {
  int front = Read_Front_Sensor();
  int right = Read_Right_Sensor();

  if (!robot_is_turning) {
    if (side_wall_detected (right)) {
      if (front_wall_detected (front)) {
        robot_is_turning = true;
        turning_right = true;
      }
      else {
        PID (right);
      }
    }
    else {
      robot_is_turning = true;
      turning_right = true;
    }
  }

  else {
    if (turning_left) {
      TurnLeftPerRight (right);
      if (!turning_left) {
        robot_is_turning = false;
      }
    }

    if (turning_right) {
      TurnRightPerRight (right);
      if (!turning_right) {
        robot_is_turning = false;
      }
    }
  }

  if (front < 340) {
    motor.MoveBackwards (MAX_LEFT , MAX_RIGHT);
    delay (150);
      motor.TurnLeft (BREAK , MAX_RIGHT);
      delay (125);
  }
}



bool waiting = false;
#define WAITING_TIME 2000

enum preparation_stage {
  PREPARATION,
  WAIT,
};
static preparation_stage turn_stage = PREPARATION;
static unsigned long action_start = 0;

void WaitTime () {

  unsigned long time = millis();

  if (turn_stage == PREPARATION) {
    Serial.println ("PREPARATION");
    action_start = time;
    turn_stage = WAIT;
  }

  if (turn_stage == WAIT) {
    Serial.println ("TURN U");
    motor.TurnAroundLeft (BREAK, BREAK);
    
    if (time - action_start >= WAITING_TIME) {
      turn_stage = PREPARATION;
      waiting = false;
      motor.MoveForwards (0 , 0);
      Serial.print ("WAITING");
    }
  }
}

bool mode_selected = false; 
bool go_per_left   = false;
bool go_per_right  = false;
bool ready         = false;





unsigned long waitStart = 0;
bool waitingStart = false;

void loop() {
  Bluetooth();

  if (button_order(PIN_LEFT)) {
    mode_selected = true;
    go_per_left   = true;
    go_per_right  = false;
  }
  else if (button_order(PIN_RIGHT)) {
    mode_selected = true;
    go_per_right  = true;
    go_per_left   = false;
  }
  else if (button_order(PIN_START)) {
    ready = true;
    waitingStart = true;         
    waitStart = millis();         
    motor.MoveForwards(0,0);
  }

  if (ready) {
    if (waitingStart) {
    
      if (millis() - waitStart >= 2000) {
        waitingStart = false;   
      } else {
        return; 
      }
    }

    
    if (mode_selected) {
      if (go_per_left) {
        FollowLeftWall();
      }
      else if (go_per_right) {
        FollowRightWall();
      }
    }
    else {
      motor.MoveForwards(MAX_LEFT , MAX_RIGHT);
    }
  }
}


















//XD

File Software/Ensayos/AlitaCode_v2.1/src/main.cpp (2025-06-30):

#include <Adafruit_SSD1306.h> 
#include <Adafruit_GFX.h>
#include <U8g2_for_Adafruit_GFX.h>
#include <CD74HC4067.h>
#include <motor.h>
#include <bitmaps_triatlon.h>
#include <progress_bars.h>
#include <multiplexedQTR.h>
#include "BluetoothSerial.h"

#define PIN_MR1 26 //primer pin motor derecho
#define PIN_MR2 27 //segundo pin motor derecho
#define PIN_ML1 16 //primer pin motor izquierdo
#define PIN_ML2 17 //segundo pin motor izquierdo

#define CHANNEL_MR1 0 //primer canal motor derecho
#define CHANNEL_MR2 1 //segundo canal motor derecho
#define CHANNEL_ML1 2 //primer canal motor izquierdo
#define CHANNEL_ML2 3 //segundo canal motor izquierdo

#define PWM_FREQUENCY 1000 //frecuencia de pulso de pwm
#define PWM_RESOLUTION 8 //resolución en bits del pwm

bool debug = true;

//Creamos el objeto motors con el metodo MotorPair de la clase Motors con sus pines, canales, frecuencia y resolución
MotorPair motors(PIN_MR1, PIN_MR2, CHANNEL_MR1, CHANNEL_MR2, PIN_ML1, PIN_ML2, 
                 CHANNEL_ML1, CHANNEL_ML2, PWM_FREQUENCY, PWM_RESOLUTION); 

BluetoothSerial SerialBT;

// Define display size in pixels
#define SCREEN_WIDTH 128
#define SCREEN_HEIGHT 64
#define OLED_RESET -1

// Define display buttons 
#define PIN_SELECT 18
#define PIN_DOWN 5

#define SPRINTER_SCREEN_MARGIN_X 35
#define SPRINTER_SCREEN_MARGIN_Y 0
#define SPRINTER_SCREEN_WIDTH 60
#define SPRINTER_SCREEN_HEIGHT 64

#define CLEANER_SCREEN_MARGIN_X 0
#define CLEANER_SCREEN_MARGIN_Y 0
#define CLEANER_SCREEN_WIDTH 128
#define CLEANER_SCREEN_HEIGHT 64

#define FIRST_SAFETY_TIMEOUT 3000
#define SECOND_SAFETY_TIMEOUT 2000

#define NUM_MODALITIES 3
#define MAX_ITEM_LENGTH 20

Adafruit_SSD1306 display(SCREEN_WIDTH, SCREEN_HEIGHT, &Wire, OLED_RESET);
U8G2_FOR_ADAFRUIT_GFX u8g2_for_adafruit_gfx;

ProgressBar displayPB(display);

// Prints a menu
void DisplayMenu(){
  if (current_screen == selection) {
    display.clearDisplay();

    // Prints previous item name
    u8g2_for_adafruit_gfx.setFontMode(1);
    u8g2_for_adafruit_gfx.setFontDirection(0);
    u8g2_for_adafruit_gfx.setForegroundColor(WHITE);
    u8g2_for_adafruit_gfx.setFont(u8g2_font_7x14_mf);
    u8g2_for_adafruit_gfx.setCursor(25, 15);
    u8g2_for_adafruit_gfx.print(F(menu_items [previous]));

    // Prints selected item name
    u8g2_for_adafruit_gfx.setFontMode(1);
    u8g2_for_adafruit_gfx.setFontDirection(0);
    u8g2_for_adafruit_gfx.setForegroundColor(WHITE);
    u8g2_for_adafruit_gfx.setFont(u8g2_font_7x14B_mf);
    u8g2_for_adafruit_gfx.setCursor(30, 37);
    u8g2_for_adafruit_gfx.print(F(menu_items [selected]));
  
    // Prints next item name
    u8g2_for_adafruit_gfx.setFontMode(1);
    u8g2_for_adafruit_gfx.setFontDirection(0);
    u8g2_for_adafruit_gfx.setForegroundColor(WHITE);
    u8g2_for_adafruit_gfx.setFont(u8g2_font_7x14_mf);
    u8g2_for_adafruit_gfx.setCursor(25, 59);
    u8g2_for_adafruit_gfx.print(F(menu_items [next]));
    
    // Prints selection frame
    display.drawXBitmap ( 0, 22, epd_bitmap_selected_background, 128, 20, WHITE);
    
    // Prints previous item icon
    display.drawXBitmap ( 4, 2, bitmap_icons[previous], 16, 16, WHITE);

    // Prints selected item icon
    display.drawXBitmap ( 4, 24, bitmap_icons[selected], 16, 16, WHITE);

    // Prints next item icon
    display.drawXBitmap ( 4, 46, bitmap_icons[next], 16, 16, WHITE);

    display.display();
  } 
  else if (current_screen == modality && selected == sprinter) {
    displayPB.load(SPRINTER_SCREEN_MARGIN_X, SPRINTER_SCREEN_MARGIN_Y, SPRINTER_SCREEN_WIDTH, SPRINTER_SCREEN_HEIGHT, FIRST_SAFETY_TIMEOUT);
    displayPB.unload(SPRINTER_SCREEN_MARGIN_X, SPRINTER_SCREEN_MARGIN_Y, SPRINTER_SCREEN_WIDTH, SPRINTER_SCREEN_HEIGHT, SECOND_SAFETY_TIMEOUT);

    current_screen = flags;
  }
  else if (current_screen == modality && selected == areaCleaner) {
    displayPB.load(CLEANER_SCREEN_MARGIN_X, CLEANER_SCREEN_MARGIN_Y, CLEANER_SCREEN_WIDTH, CLEANER_SCREEN_HEIGHT, FIRST_SAFETY_TIMEOUT);   
    displayPB.unload(CLEANER_SCREEN_MARGIN_X, CLEANER_SCREEN_MARGIN_Y, CLEANER_SCREEN_WIDTH, CLEANER_SCREEN_HEIGHT, SECOND_SAFETY_TIMEOUT);

    current_screen = flags;
  }
  else if (current_screen == flags){
    display.clearDisplay();
    display.drawXBitmap( 0, 0, epd_bitmap_flag, 128, 64, WHITE);
    display.display();
  }
  else if (current_screen == modality && selected == sumo){
    /*if (!Ps3.isConnected()) {
      display.clearDisplay();
      display.drawXBitmap( 0, 0, bitmap_screens[selected], 128, 64, WHITE);
      display.display();

      delay(250);

      display.clearDisplay();
      display.display();

      delay(250);
    } else {*/
      display.clearDisplay();
      display.drawXBitmap( 0, 0, bitmap_screens[selected], 128, 64, WHITE);
      display.display();
    //}
  }
  else if (current_screen == modality && selected == sprinter){
    display.clearDisplay();
    display.drawXBitmap( 0, 0, bitmap_screens[selected], 128, 64, WHITE);
    display.display();
  }

  UpdateScreenStatus();

  if (current_screen == selection){  
    motors.StayStill();
  }
}



//---------------------------------------------------------------------------------------------   

//Para los motores usamos una lirería propia
//motors.MoveForwards (MID_SPEED , MID_SPEED) se indica la dirección y el PWM de cada rueda
//motors.StayStill() baja a 0 los PWM de cada rueda
//motors.Brake() pone en corto los drivers

int datoBT;

#define QRE_BLACK          3900
#define SHARP_ATAQUE       1000
#define SET_BACKWARDS_TIME  350 

#define LOW_SPEED   100
#define MID_SPEED   150
#define FULL_SPEED  200

#define INCREASE_SPEED        10 
#define INCREASE_SPEED_DELAY 500

bool offRoad;



int sharp_left;
int sharp_right;
int sharp_front_right;
int sharp_front;
int sharp_front_left;

int any_qre_front;
bool qre_front;
bool qre_back;

int signal_input;

CD74HC4067 my_mux(4, 25, 33, 32); // s0, s1, s2, s3

#define PIN_SIG 34
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
